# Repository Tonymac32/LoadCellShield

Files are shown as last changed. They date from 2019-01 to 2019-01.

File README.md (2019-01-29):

# LoadCellShield
Dual INA125 Instrumentation Amplifier Shield

This is a 2-channel Instrumentation Amplifier shield based on the Burr-Brown INA125: http://www.ti.com/product/INA125

The purpose of creating it was to monitor 2 load cells at higher speed than possible with the usual sensors, however it can be used to monitor any bridge-based sensor.

Help keep me free to do this sort of thing:
[Donate Here][paypal]

[paypal]: https://www.paypal.com/cgi-bin/webscr?cmd=_s-xclick&hosted_button_id=6JRRCSB28828Y&source=url

## Profile

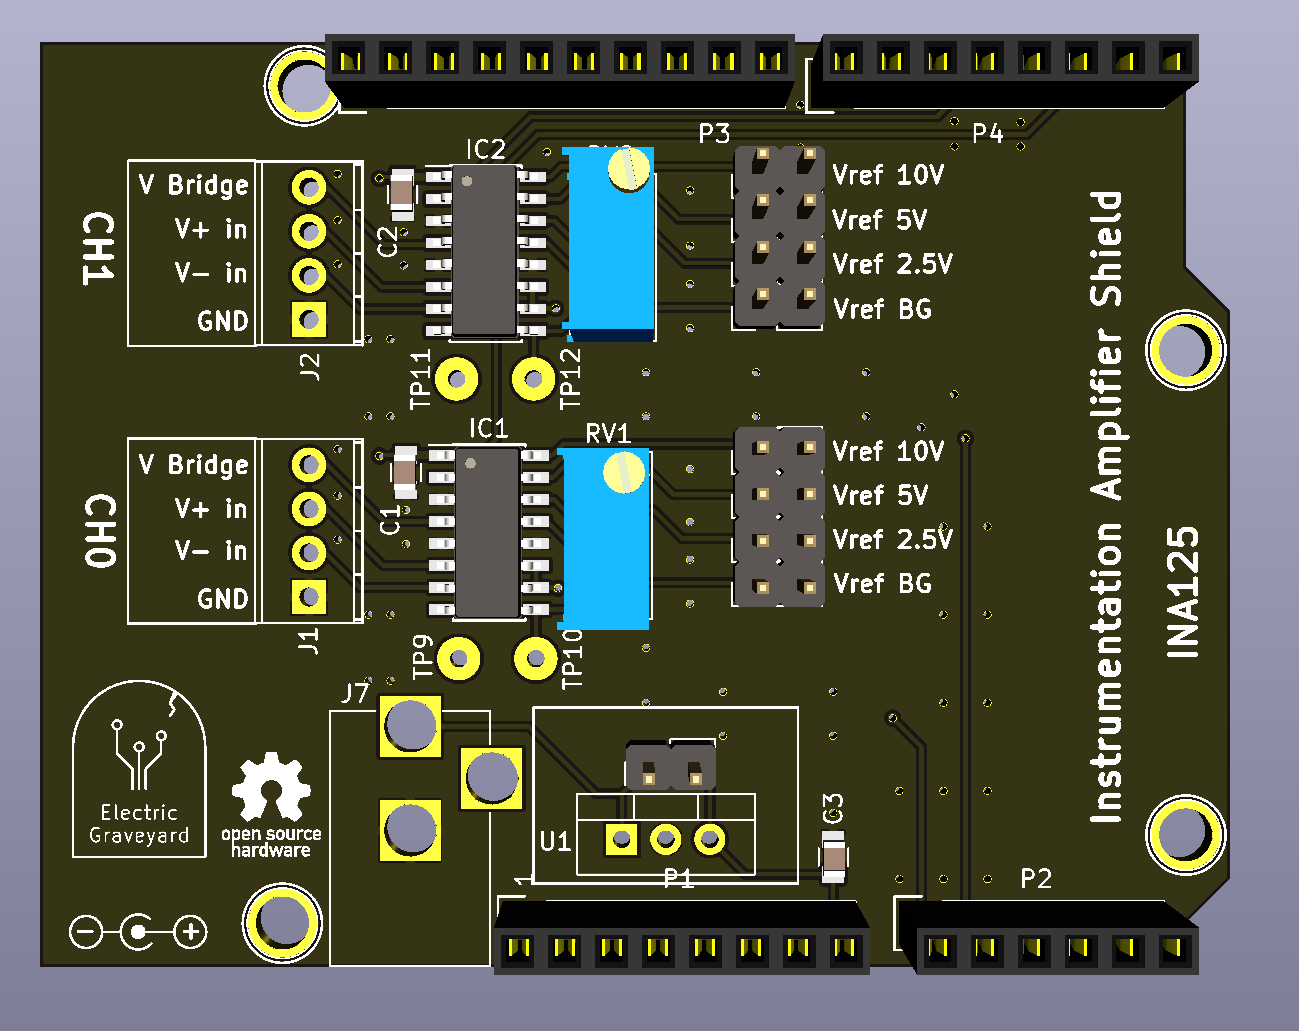
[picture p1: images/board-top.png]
board


## Usage

The board was designed for flexibility:  It can power the Arduino, the Arduino (or compatible) can power it.  

U1 offers adequate space for a linear regulator, a DC-DC converter, or a simple jumper in case regulation is not necessary.

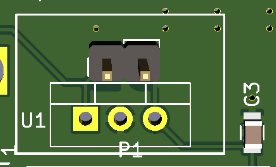
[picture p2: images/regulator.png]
regulator


Test Points `1..4` and `5..8` are the Vref selection for the two channels.  

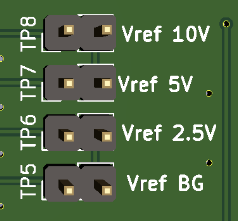
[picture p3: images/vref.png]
Vref


TP `9..10` and `11..12` allow for either testing the value of RV1 and RV2 gain potentiometers, or for adding a resistor to set a fixed gain, leaving RV1 and RV2 either unpopulated or swapped for trimming.

gain

Digital I/O 2 and 4 control Channel 0 and Channel 1 amplifier enable, allowing power-down modes

Analog output is presented to Arduino A0 and A1.

## Operating Advisory

The INA125 can operate at high voltages, and can likewise output high voltages.  This design does not currently provide any protection for the Arduino input.

Operating requirements:

* Vin must be higher than the desired Vref.  
    * If Vin is higher than the Arduino-compatible can handle, then a regulator or a dual supply must be used.
    * Higher Vref will result in higher output to the Analog Input of the microcontroller
* Maximum possible output from the amplifier must be within the specification for the Arduino Input.
    * Values vary per board, be certain to check.
    * Reference product page linked above for output characteristics
    
## Tested Configurations (Gain set according to datasheet to be less than max input for boards)

Arduino Uno R3:
* 12V Vin
* Vref 5V
* 3mV/V load cell

Adafruit Metro M4 Express:
* 5V Vin
* Vref 2.5V
* 3mV/V load cell

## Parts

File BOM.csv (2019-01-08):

Bill Of Materials
C1 | 0.1 uF | 0805
C2 | 0.1 uF | 0805
C3 | 1 uF | 0805
IC1 | INA125 | SO-16
IC2 | INA125 | SO-16
J1 | Phoenix MPT 2.54 4-pole
J2 | Phoenix MPT 2.54 4-pole
J3 | 2.54 mm header, 7 position
J4 | 2.54 mm header, 6 position
J5 | 2.54 mm header, 10 position
J6 | 2.54 mm header, 8 position
J7 | Barrel Jack CP-002A-ND or equivalent
RV1 | Bourns 3296Y Potentiometer
RV2 | Bourns 3296Y Potentiometer
TP1 | 2.54 mm header, 2 position
TP2 | 2.54 mm header, 2 position
TP3 | 2.54 mm header, 2 position
TP4 | 2.54 mm header, 2 position
TP5 | 2.54 mm header, 2 position
TP6 | 2.54 mm header, 2 position
TP7 | 2.54 mm header, 2 position
TP8 | 2.54 mm header, 2 position
U1 | LM7805

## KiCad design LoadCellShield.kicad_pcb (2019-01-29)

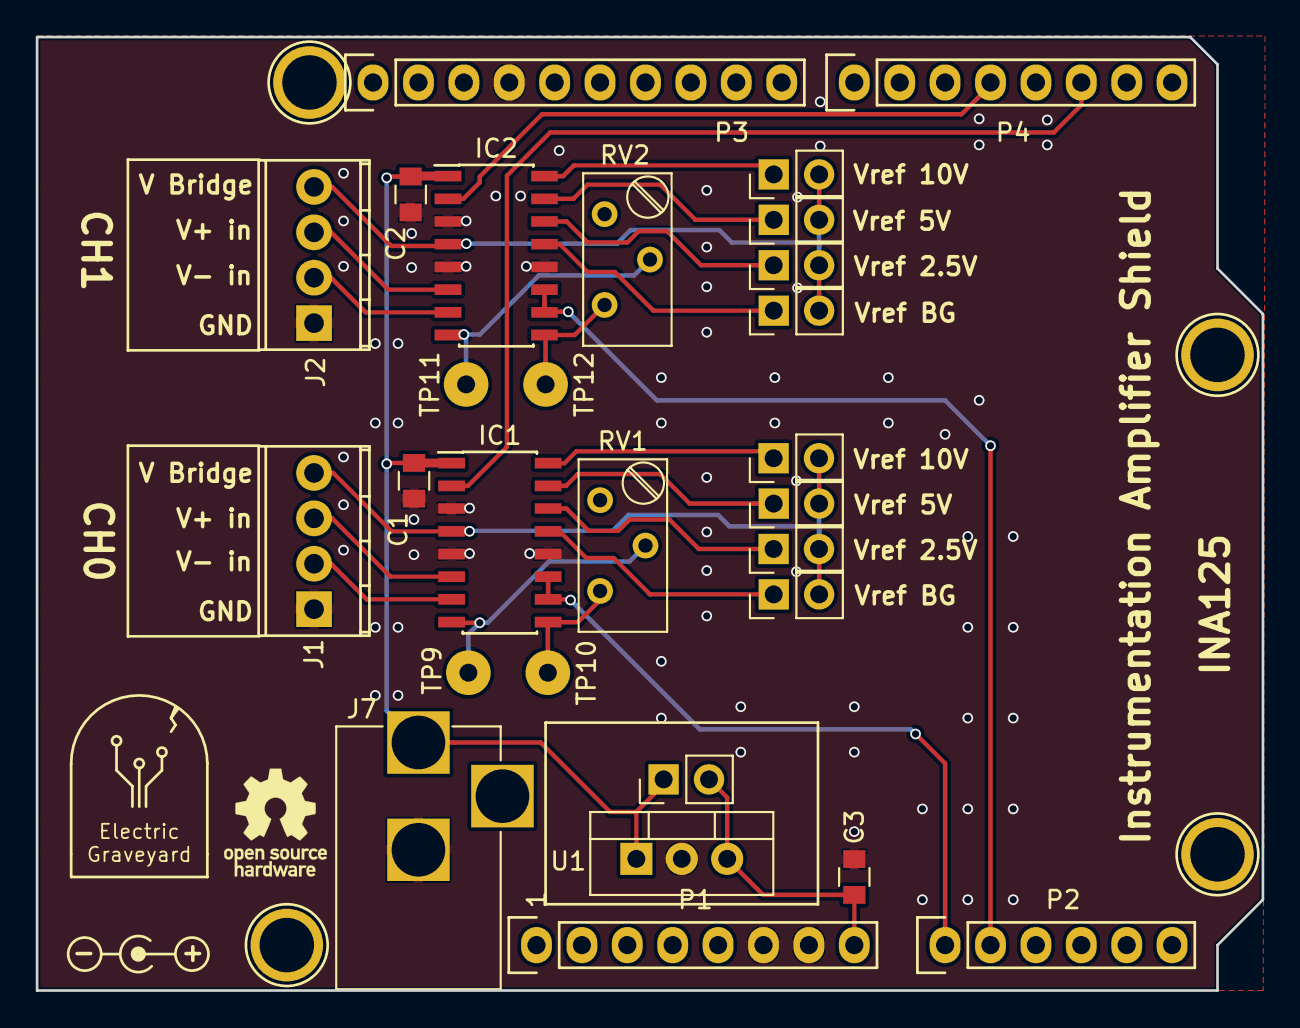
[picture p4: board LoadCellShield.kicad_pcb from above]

Board: 2 copper layers, 68.6 x 53.3 mm, 31 parts (0 on the bottom side), 27 nets.

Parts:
C1, C2, C3: C; C_0805
IC1, IC2: INA125; SOIC-16_3.9x9.9mm_Pitch1.27mm
J1, J2: Screw_Terminal_01x04; TerminalBlock_Phoenix_MPT-2.54mm_4pol
J7: Barrel_Jack_Switch; BARREL_JACK
P1: Power; Socket_Strip_Arduino_1x08
P2: Analog; Socket_Strip_Arduino_1x06
P3: Digital; Socket_Strip_Arduino_1x10
P4: Digital; Socket_Strip_Arduino_1x08
P5, P6, P7, P8: CONN_01X01; Arduino_1pin
RV1, RV2: R_POT; Potentiometer_Trimmer_Bourns_3296Y
TP1, TP2, TP3, TP4, TP5, TP6, TP7, TP8: TestPoint_2Pole; Pin_Header_Straight_1x02_Pitch2.54mm
TP9, TP10, TP11, TP12: TestPoint; SolderWirePad_single_1mmDrill
U1: R-78E5.0-0.5; TO-220-3_Vertical

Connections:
/A4(SDA): P2.5, P3.2
/A5(SCL): P2.6, P3.1
Analog_Vin: C1.1, C2.1, IC1.1, IC2.1, J7.1, U1.1
Channel0: IC1.10, IC1.11, P2.1
Channel1: IC2.10, IC2.11, P2.2
GND: C1.2, C2.2, C3.2, IC1.3, IC1.5, IC1.12, IC2.3, IC2.5, IC2.12, J1.1, J2.1, J7.2, P1.6, P1.7, P3.4, U1.2
unnamed: IC1.6, J1.3
unnamed: IC1.7, J1.2
unnamed: IC1.8, RV1.2, TP9.1
unnamed: IC1.9, RV1.3, TP10.1
unnamed: IC1.13, TP5.1
unnamed: IC1.14, TP6.1
unnamed: IC1.15, TP7.1
unnamed: IC1.16, TP8.1
unnamed: IC2.6, J2.3
unnamed: IC2.7, J2.2
unnamed: IC2.8, RV2.2, TP11.1
unnamed: IC2.9, RV2.3, TP12.1
unnamed: IC2.13, TP1.1
unnamed: IC2.14, TP2.1
unnamed: IC2.15, TP3.1
unnamed: IC2.16, TP4.1
Sleep0: IC1.2, P4.6
Sleep1: IC2.2, P4.4
V_Bridge0: IC1.4, J1.4, TP5.2, TP6.2, TP7.2, TP8.2
V_Bridge1: IC2.4, J2.4, TP1.2, TP2.2, TP3.2, TP4.2
Vin: C3.1, P1.8, U1.3

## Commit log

2019-01-08 Add board image
    How it looks like.
2019-01-08 Create BOM.csv
    Simple reference BOM
    [BOM.csv]
2019-01-08 Update BOM.csv
    package sizes
    [BOM.csv]
2019-01-08 Update BOM.csv
    formatting fix
    [BOM.csv]
2019-01-08 Gerbers
    Gerber files
    [LoadCellShield-B.Cu.gbr, LoadCellShield-B.Mask.gbr, LoadCellShield-B.SilkS.gbr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]
2019-01-29 Revise Layout to simplify build
    Assembling these was a pain because of the 8x 2 position headers. Squashed them so 2x 8 position ones will work. Also some improvements to general routing.
    [LoadCellShield-B.Cu.gbr, LoadCellShield-B.Mask.gbr, LoadCellShield-B.SilkS.gbr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]
2019-01-30 Update board-top.png
    update documentation to match routing.
